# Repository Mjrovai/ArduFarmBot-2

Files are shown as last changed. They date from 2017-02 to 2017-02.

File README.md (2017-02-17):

# ArduFarmBot-2
Automatic Gardening System with NodeMCU and Blynk
<p> This complete tutorial can be found at: https://www.instructables.com/id/Automatic-Gardening-System-With-NodeMCU-and-Blynk-/ </p>
<p>Some time ago, we developed a similar project: <a href="https://www.instructables.com/id/ArduFarmBot-Controlling-a-Tomato-Home-Farm-Using-A/">"ArduFarmBot: Controlling a Tomato Home Farm using Arduino and IoT"</a>. On this new version, the <strong><em>ArduFarmBot 2,</em></strong> the main specification of the original project will be kept. We will develop a fully automated Gardening System based on NodeMCU ESP8266 and an IoT app, the BLYNK. </p><p>Basically, information from a plantation will be captured, temperature and humidity, both from air and soil. Based on those data, the ArduFarmBot 2 will decide the right amount (and when) the plantation should receive heat and water. Also the project should allow manual intervention of an operator in order to control a water pump and an electric lamp to generate heat for the plantation. The manual intervention must be both, local and remote via Internet.</p><p>In short, the system should receive as<strong> input</strong>:</p><ul>           
<li>Sensors:           
<ul>           
<li>Air Temperature               
</li><li>Air Relative Humidity                     
</li><li>Soil Temperature
</li><li>Soil Moisture (humidity)</li></ul></li></ul><ul> 
<li>Buttons:           
<ul>           
<li>Pump ON/OFF              
</li><li>Lamp ON/OFF</li></ul></li></ul><p>The system should provide as an <strong>output</strong>:</p><ul>           
<li>Actuators:           
<ul>           
<li>Relay for Pump control              
</li><li>Relay for Lamp control</li></ul></li></ul><ul> 
<li>Messages
<ul>
<li>Automatic messages must be sent on main events as:
<ul>
<li>Pump ON
</li><li>Lamo On
</li><li>System Off-line </li></ul></li></ul></li></ul><ul>
<li>Data Display           
<ul>           
<li>All analog and digital data should be available for instant  evaluation</li></ul></li></ul><ul> 
<li>Data Storage
<ul>
<li>
<p>Historic data should be storage remotely</p></li></ul></li></ul><p>The block diagram shows the main components of the project.</p>

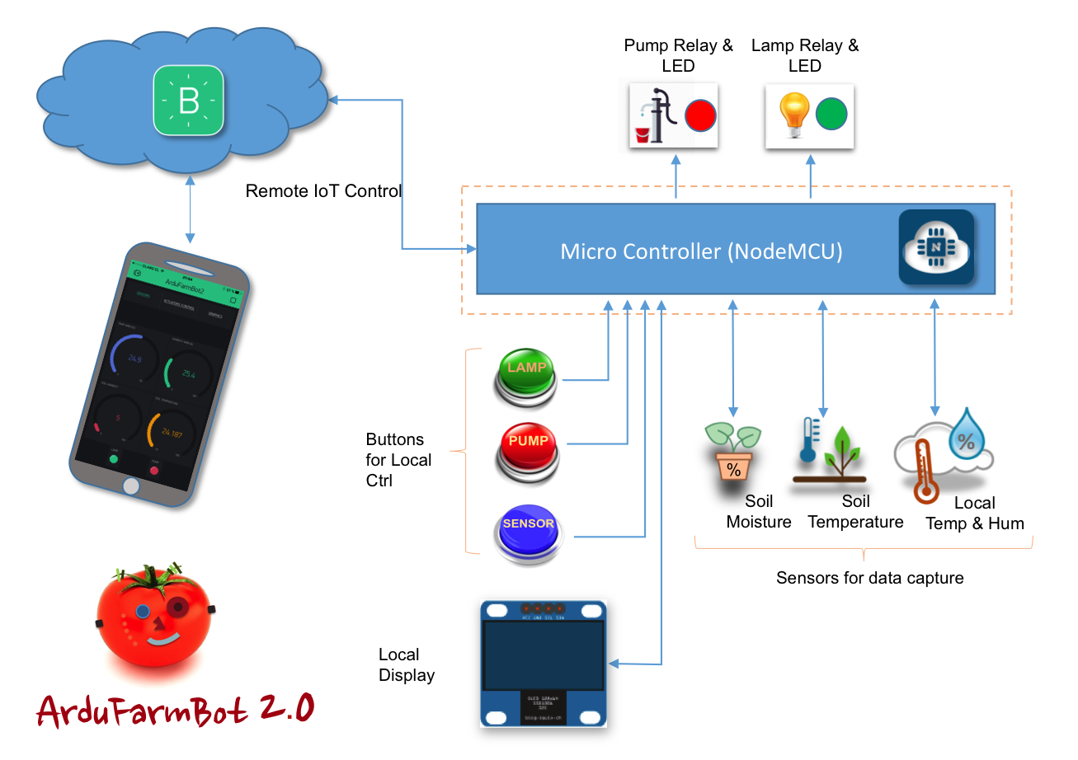
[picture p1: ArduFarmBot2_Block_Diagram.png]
ArduFarmBot2 Block Diagram


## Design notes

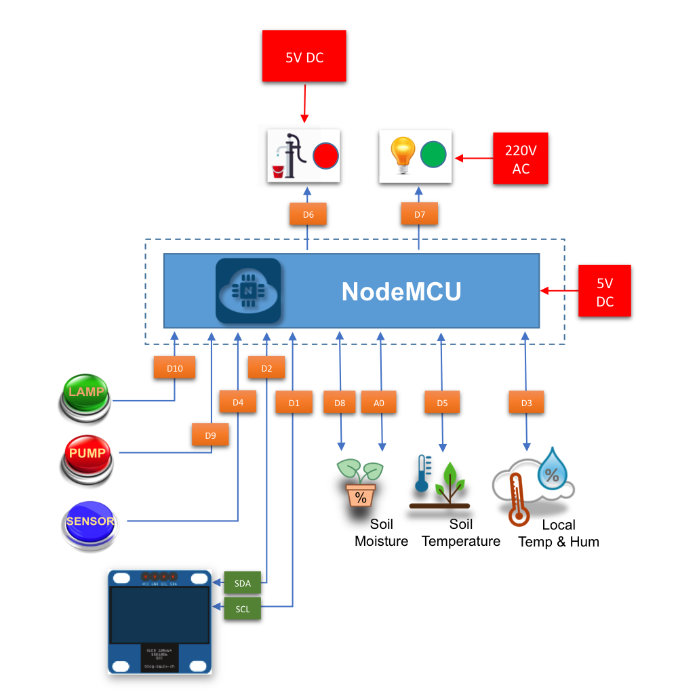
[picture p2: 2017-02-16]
ArduFarmBot2_Pin_Diagram.png

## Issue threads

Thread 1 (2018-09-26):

LM393 Soil moisture value.

juliobarbagallo, 2018-09-26:
Hi Marcelo,
    How are you?
I am not pretty sure if its an issue, but its the only way I figured it out to contact you.
This is my first time trying on IoT projects and I am trying to follow yours. Thanks for sharing it.
I need to see if you can help me out here, I was perfect until Soil Moisture step. Didn't try it at soil, just in the air, but I got Soil= -169% I am not sure what I am doing wrong. If you could try to guide me here would be great.
Thanks in advance and thanks again for sharing, I am really amused with your work.
Regards. Julio.
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

drinkwater2018, 2018-09-29:
Hi Mjrovai,

I am also on same page, its taking hell of time to figure out what's wrong
in the code and my sensor, I am not able to exicute the out for wifi and
for relay I installed driver for.wifi and i still not able to follow the
words mjbot forum.

Please help me you reached next level, I have extactly did what you did but
not any thing further, I thank you for followup I hope we can both figure
it out and resolve the issue and learn

Thanks
Water

On Wed, Sep 26, 2018, 6:38 PM juliobarbagallo <notifications@github.com>
wrote:

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

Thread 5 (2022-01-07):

Error in compiling in Mac OSX: ESP8266WiFi and DHT22

andreltr, 2022-01-07:
Hello,

I'm trying to compile the software on my Macbook Pro to no avail.
Settings:
Additional URLs: https://arduino.esp8266.com/stable/package_esp8266com_index.json,https://dl.espressif.com/dl/package_esp32_index.json,http://arduino.esp8266.com/stable/package_esp8266com_index.json,https://raw.githubusercontent.com/esp8266/esp8266.github.io/master/stable/package_esp8266com_index.json

The errors are shown below,

Board:
ESP32 Dev Module

The error appears in the following line:

/* ESP */
#include <ESP8266WiFi.h>

Arduino: 1.8.20 Hourly Build 2021/12/20 07:34 (Mac OS X), Board: "ESP32 Dev Module, Disabled, Default 4MB with spiffs (1.2MB APP/1.5MB SPIFFS), 240MHz (WiFi/BT), QIO, 80MHz, 4MB (32Mb), 921600, None"
ArduFarmBot2_Local_Automatic_Ctrl_V2:18:25: fatal error: ESP8266WiFi.h: No such file or directory
compilation terminated.
exit status 1
ESP8266WiFi.h: No such file or directory

Board:
Generic ESP8266 Module

Error shown in stationDefines.h:
Arduino: 1.8.20 Hourly Build 2021/12/20 07:34 (Mac OS X), Board: "Generic ESP8266 Module, 80 MHz, Flash, Disabled (new aborts on oom), Disabled, All SSL ciphers (most compatible), 32KB cache + 32KB IRAM (balanced), Use pgm_read macros for IRAM/PROGMEM, dtr (aka nodemcu), 26 MHz, 40MHz, DOUT (compatible), 1MB (FS:64KB OTA:~470KB), 2, nonos-sdk 2.2.1+100 (190703), v2 Lower Memory, Disabled, None, Only Sketch, 115200"

In file included from /Users/andreltr/Documents/IoT/Garduino/Automatic Gardening System With NodeMCU and Blynk/github_v2/ArduFarmBot2_Local_Automatic_Ctrl_V2/ArduFarmBot2_Local_Automatic_Ctrl_V2.ino:15:
stationDefines.h:23:16: error: 'D3' was not declared in this scope
   23 | #define DHTPIN D3
      |                ^~
/Users/andreltr/Documents/IoT/Garduino/Automatic Gardening System With NodeMCU and Blynk/github_v2/ArduFarmBot2_Local_Automatic_Ctrl_V2/ArduFarmBot2_Local_Automatic_Ctrl_V2.ino:31:9: note: in expansion of macro 'DHTPIN'
   31 | DHT dht(DHTPIN, DHTTYPE);
      |         ^~~~~~
/Users/andreltr/Documents/IoT/Garduino/Automatic Gardening System With NodeMCU and Blynk/github_v2/ArduFarmBot2_Local_Automatic_Ctrl_V2/ArduFarmBot2_Local_Automatic_Ctrl_V2.ino: In function 'void setup()':
stationDefines.h:38:18: error: 'D6' was not declared in this scope
   38 | #define PUMP_PIN D6              //PUMP (Red LED)
      |                  ^~
/Users/andreltr/Documents/IoT/Garduino/Automatic Gardening System With NodeMCU and Blynk/github_v2/ArduFarmBot2_Local_Automatic_Ctrl_V2/ArduFarmBot2_Local_Automatic_Ctrl_V2.ino:47:11: note: in expansion of macro 'PUMP_PIN'
   47 |   pinMode(PUMP_PIN, OUTPUT);
      |           ^~~~~~~~
stationDefines.h:39:18: error: 'D7' was not declared in this scope
   39 | #define LAMP_PIN D7              //LAMP (Green LED)
      |                  ^~
/Users/andreltr/Documents/IoT/Garduino/Automatic Gardening System With NodeMCU and Blynk/github_v2/ArduFarmBot2_Local_Automatic_Ctrl_V2/ArduFarmBot2_Local_Automatic_Ctrl_V2.ino:48:11: note: in expansion of macro 'LAMP_PIN'
   48 |   pinMode(LAMP_PIN, OUTPUT);
      |           ^~~~~~~~
stationDefines.h:44:24: error: 'D9' was not declared in this scope
   44 | #define PUMP_ON_BUTTON D9        //push-button PUMP (Red)
      |                        ^~
/Users/andreltr/Documents/IoT/Garduino/Automatic Gardening System With NodeMCU and Blynk/github_v2/ArduFarmBot2_Local_Automatic_Ctrl_V2/ArduFarmBot2_Local_Automatic_Ctrl_V2.ino:49:11: note: in expansion of macro 'PUMP_ON_BUTTON'
   49 |   pinMode(PUMP_ON_BUTTON, INPUT_PULLUP);
      |           ^~~~~~~~~~~~~~
stationDefines.h:45:24: error: 'D10' was not declared in this scope; did you mean 'B10'?
   45 | #define LAMP_ON_BUTTON D10       //push-button LAMP (Green)
      |                        ^~~
/Users/andreltr/Documents/IoT/Garduino/Automatic Gardening System With NodeMCU and Blynk/github_v2/ArduFarmBot2_Local_Automatic_Ctrl_V2/ArduFarmBot2_Local_Automatic_Ctrl_V2.ino:50:11: note: in expansion of macro 'LAMP_ON_BUTTON'
   50 |   pinMode(LAMP_ON_BUTTON, INPUT_PULLUP);
      |           ^~~~~~~~~~~~~~
stationDefines.h:46:29: error: 'D4' was not declared in this scope
   46 | #define SENSORS_READ_BUTTON D4   //push-button SENSOR (yellow)
      |                             ^~
/Users/andreltr/Documents/IoT/Garduino/Automatic Gardening System With NodeMCU and Blynk/github_v2/ArduFarmBot2_Local_Automatic_Ctrl_V2/ArduFarmBot2_Local_Automatic_Ctrl_V2.ino:51:11: note: in expansion of macro 'SENSORS_READ_BUTTON'
   51 |   pinMode(SENSORS_READ_BUTTON, INPUT_PULLUP);
      |           ^~~~~~~~~~~~~~~~~~~
stationDefines.h:30:24: error: 'D8' was not declared in this scope; did you mean 's8'?
   30 | #define soilMoisterVcc D8
      |                        ^~
/Users/andreltr/Documents/IoT/Garduino/Automatic Gardening System With NodeMCU and Blynk/github_v2/ArduFarmBot2_Local_Automatic_Ctrl_V2/ArduFarmBot2_Local_Automatic_Ctrl_V2.ino:52:11: note: in expansion of macro 'soilMoisterVcc'
   52 |   pinMode(soilMoisterVcc, OUTPUT);
      |           ^~~~~~~~~~~~~~
/Users/andreltr/Documents/IoT/Garduino/Automatic Gardening System With NodeMCU and Blynk/github_v2/ArduFarmBot2_Local_Automatic_Ctrl_V2/ArduFarmBot2_Local_Automatic_Ctrl_V2.ino: In function 'void readLocalCmd()':
stationDefines.h:44:24: error: 'D9' was not declared in this scope
   44 | #define PUMP_ON_BUTTON D9        //push-button PUMP (Red)
      |                        ^~
/Users/andreltr/Documents/IoT/Garduino/Automatic Gardening System With NodeMCU and Blynk/github_v2/ArduFarmBot2_Local_Automatic_Ctrl_V2/ArduFarmBot2_Local_Automatic_Ctrl_V2.ino:77:32: note: in expansion of macro 'PUMP_ON_BUTTON'
   77 |   boolean digiValue = debounce(PUMP_ON_BUTTON);
      |                                ^~~~~~~~~~~~~~
stationDefines.h:45:24: error: 'D10' was not declared in this scope; did you mean 'B10'?
   45 | #define LAMP_ON_BUTTON D10       //push-button LAMP (Green)
      |                        ^~~
/Users/andreltr/Documents/IoT/Garduino/Automatic Gardening System With NodeMCU and Blynk/github_v2/ArduFarmBot2_Local_Automatic_Ctrl_V2/ArduFarmBot2_Local_Automatic_Ctrl_V2.ino:84:24: note: in expansion of macro 'LAMP_ON_BUTTON'
   84 |   digiValue = debounce(LAMP_ON_BUTTON);
      |                        ^~~~~~~~~~~~~~
stationDefines.h:46:29: error: 'D4' was not declared in this scope
   46 | #define SENSORS_READ_BUTTON D4   //push-button SENSOR (yellow)
      |                             ^~
/Users/andreltr/Documents/IoT/Garduino/Automatic Gardening System With NodeMCU and Blynk/github_v2/ArduFarmBot2_Local_Automatic_Ctrl_V2/ArduFarmBot2_Local_Automatic_Ctrl_V2.ino:91:24: note: in expansion of macro 'SENSORS_READ_BUTTON'
   91 |   digiValue = debounce(SENSORS_READ_BUTTON);
      |                        ^~~~~~~~~~~~~~~~~~~
/Users/andreltr/Documents/IoT/Garduino/Automatic Gardening System With NodeMCU and Blynk/github_v2/ArduFarmBot2_Local_Automatic_Ctrl_V2/ArduFarmBot2_Local_Automatic_Ctrl_V2.ino: In function 'void aplyCmd()':
stationDefines.h:38:18: error: 'D6' was not declared in this scope
   38 | #define PUMP_PIN D6              //PUMP (Red LED)
      |                  ^~
/Users/andreltr/Documents/IoT/Garduino/Automatic Gardening System With NodeMCU and Blynk/github_v2/ArduFarmBot2_Local_Automatic_Ctrl_V2/ArduFarmBot2_Local_Automatic_Ctrl_V2.ino:114:18: note: in expansion of macro 'PUMP_PIN'
  114 |     digitalWrite(PUMP_PIN, HIGH);
      |                  ^~~~~~~~
stationDefines.h:38:18: error: 'D6' was not declared in this scope
   38 | #define PUMP_PIN D6              //PUMP (Red LED)
      |                  ^~
/Users/andreltr/Documents/IoT/Garduino/Automatic Gardening System With NodeMCU and Blynk/github_v2/ArduFarmBot2_Local_Automatic_Ctrl_V2/ArduFarmBot2_Local_Automatic_Ctrl_V2.ino:119:22: note: in expansion of macro 'PUMP_PIN'
  119 |         digitalWrite(PUMP_PIN, LOW);
      |                      ^~~~~~~~
stationDefines.h:39:18: error: 'D7' was not declared in this scope
   39 | #define LAMP_PIN D7              //LAMP (Green LED)
      |                  ^~
/Users/andreltr/Documents/IoT/Garduino/Automatic Gardening System With NodeMCU and Blynk/github_v2/ArduFarmBot2_Local_Automatic_Ctrl_V2/ArduFarmBot2_Local_Automatic_Ctrl_V2.ino:125:18: note: in expansion of macro 'LAMP_PIN'
  125 |     digitalWrite(LAMP_PIN, HIGH);
      |                  ^~~~~~~~
stationDefines.h:39:18: error: 'D7' was not declared in this scope
   39 | #define LAMP_PIN D7              //LAMP (Green LED)
      |                  ^~
/Users/andreltr/Documents/IoT/Garduino/Automatic Gardening System With NodeMCU and Blynk/github_v2/ArduFarmBot2_Local_Automatic_Ctrl_V2/ArduFarmBot2_Local_Automatic_Ctrl_V2.ino:130:22: note: in expansion of macro 'LAMP_PIN'
  130 |         digitalWrite(LAMP_PIN, LOW);
      |                      ^~~~~~~~
/Users/andreltr/Documents/IoT/Garduino/Automatic Gardening System With NodeMCU and Blynk/github_v2/ArduFarmBot2_Local_Automatic_Ctrl_V2/generalFunctions.ino: In function 'void waitButtonPress(int)':
stationDefines.h:46:29: error: 'D4' was not declared in this scope
   46 | #define SENSORS_READ_BUTTON D4   //push-button SENSOR (yellow)
      |                             ^~
/Users/andreltr/Documents/IoT/Garduino/Automatic Gardening System With NodeMCU and Blynk/github_v2/ArduFarmBot2_Local_Automatic_Ctrl_V2/generalFunctions.ino:8:19: note: in expansion of macro 'SENSORS_READ_BUTTON'
    8 |   while (debounce(SENSORS_READ_BUTTON))
      |                   ^~~~~~~~~~~~~~~~~~~
/Users/andreltr/Documents/IoT/Garduino/Automatic Gardening System With NodeMCU and Blynk/github_v2/ArduFarmBot2_Local_Automatic_Ctrl_V2/getSensors.ino: In function 'void getSoilMoisterData()':
stationDefines.h:30:24: error: 'D8' was not declared in this scope; did you mean 's8'?
   30 | #define soilMoisterVcc D8
      |                        ^~
/Users/andreltr/Documents/IoT/Garduino/Automatic Gardening System With NodeMCU and Blynk/github_v2/ArduFarmBot2_Local_Automatic_Ctrl_V2/getSensors.ino:25:17: note: in expansion of macro 'soilMoisterVcc'
   25 |   digitalWrite (soilMoisterVcc, HIGH);
      |                 ^~~~~~~~~~~~~~
exit status 1
'D3' was not declared in this scope

Board NodeMCU 1.0 (ESP-12E Module)

Error shown

Arduino: 1.8.20 Hourly Build 2021/12/20 07:34 (Mac OS X), Board: "Generic ESP8266 Module, 80 MHz, Flash, Disabled (new aborts on oom), Disabled, All SSL ciphers (most compatible), 32KB cache + 32KB IRAM (balanced), Use pgm_read macros for IRAM/PROGMEM, dtr (aka nodemcu), 26 MHz, 40MHz, DOUT (compatible), 1MB (FS:64KB OTA:~470KB), 2, nonos-sdk 2.2.1+100 (190703), v2 Lower Memory, Disabled, None, Only Sketch, 115200"

fork/exec /Users/andreltr/Library/Arduino15/packages/esp8266/tools/xtensa-lx106-elf-gcc/3.0.3-gcc10.3-9bcba0b/bin/xtensa-lx106-elf-g++: no such file or directory
Error compiling for board NodeMCU 1.0 (ESP-12E Module).
Could not find boards.txt in /Users/andreltr/Library/Arduino15/packages/esp8266/hardware/esp8266/3.0.2. Is it pre-1.5?

Question: what is the correct board to use or which setting/library is missing, please?

André Luiz

andreltr, 2022-01-08:
Hello,
I found the correct board and it is NodeMCU 1.0 (ESP 12E Module).
All problems solved.

Closed 2022-01-08.

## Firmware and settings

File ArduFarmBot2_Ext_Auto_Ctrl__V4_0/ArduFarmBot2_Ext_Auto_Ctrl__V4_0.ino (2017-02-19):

/***************************************************************************************************************
 *  ArduFarmBot using NodeMCU ESP-12 Develop Kit V1.0
 *  DHT connected to NodeMCU pin D3 (Ambient Temperature and Relative Humidity)
 *  Soil Moister Sensor connected to A0
 *  Sensor Data on local OLED Display
 *  Local Command via buttons 
 *  OLED Display is off as default. Press Sensor Button to update and display data
 *  Introduced the function "waitButtonPress (int waitTime)", to break initial loop
 *  Automatic Local Control
 *  Display automatic set-up parameters at Start-up
 *  Sensor data sent to Blynk app
 *  Control commands received from Blynk app
 *  Downloads, docs, tutorials: http://www.blynk.cc
 *  Blynk library is licensed under MIT license
 *  
 *  V4.0 Invert the logic to use Relay module that works from HIGH to LOW
 *       
 *  MJRoBot Version 4.0 - Automatic and Remote Control - Logic LOW -  Developed by MJRovai 16 Feb 2017
 ********************************************************************************************************************************/
#define SW_VERSION "   SW Ver. 4.0" // SW version will appears at innitial LCD Display
#include "stationDefines.h"       // Project definitions
#include "stationCredentials.h"

/* ESP & Blynk */
#define BLYNK_PRINT Serial    // Comment this out to disable prints and save space
#include <ESP8266WiFi.h>
#include <BlynkSimpleEsp8266.h>
WidgetLED PUMPs(V0);  // Echo signal to Sensors Tab at Blynk App
WidgetLED PUMPa(V5); // Echo signal to Actuators Tab at Blynk App
WidgetLED LAMPs(V1);  // Echo signal to Sensors Tab at Blynk App
WidgetLED LAMPa(V6); // Echo signal to Actuators Tab at Blynk App

/* TIMER */
#include <SimpleTimer.h>
SimpleTimer timer;

/* OLED */
#include <ACROBOTIC_SSD1306.h> // library for OLED: SCL ==> D1; SDA ==> D2
#include <SPI.h>
#include <Wire.h>

/* DHT22*/
#include "DHT.h"
DHT dht(DHTPIN, DHTTYPE);

/* DS18B20 Temperature Sensor */
#include <OneWire.h>
#include <DallasTemperature.h>
OneWire oneWire(ONE_WIRE_BUS);
DallasTemperature DS18B20(&oneWire);

void setup()
{
  Serial.begin(115200);
  delay(10);
  Serial.println("ArduFarmBot 2");
  Serial.println(".... Starting Setup");
  Serial.println(" ");

  pinMode(PUMP_PIN, OUTPUT);
  pinMode(LAMP_PIN, OUTPUT);
  pinMode(PUMP_ON_BUTTON, INPUT_PULLUP);
  pinMode(LAMP_ON_BUTTON, INPUT_PULLUP);
  pinMode(SENSORS_READ_BUTTON, INPUT_PULLUP);
  pinMode(soilMoisterVcc, OUTPUT);
  
  Blynk.begin(auth, ssid, pass);
  oledStart();
  dht.begin();
  DS18B20.begin();

  PUMPs.off();
  LAMPs.off();
  PUMPa.off();
  LAMPa.off();
  digitalWrite(PUMP_PIN, HIGH); // To be used with Relay module (inverted logic: normally HIGH)
  digitalWrite(LAMP_PIN, HIGH); // To be used with Relay module (inverted logic: normally HIGH)
  digitalWrite (soilMoisterVcc, LOW);
  
  waitButtonPress (SHOW_SET_UP); // Wait for Sensor Button to be pressed 
  oled.clearDisplay();
  startTimers();
}

void loop()
{
  timer.run(); // Initiates SimpleTimer
  Blynk.run();
}

/****************************************************************
* Read remote commands 
****************************************************************/
BLYNK_WRITE(3) // Pump remote control
{
  int i=param.asInt();
  if (i==1) 
  {
    pumpStatus = !pumpStatus;
    aplyCmd();
  }
}

BLYNK_WRITE(4) // Lamp remote control
{
  int i=param.asInt();
  if (i==1) 
  {
    lampStatus = !lampStatus;
    aplyCmd();
  }
}

/****************************************************************
* Read local commands (Pump and Lamp buttons are normally "HIGH"):
****************************************************************/
void readLocalCmd() 
{  
  boolean digiValue = debounce(PUMP_ON_BUTTON);
  if (!digiValue) 
  {
    pumpStatus = !pumpStatus;
    aplyCmd();
  }

  digiValue = debounce(LAMP_ON_BUTTON);
  if (!digiValue) 
  {
    lampStatus = !lampStatus;
    aplyCmd();
  }

  digiValue = debounce(SENSORS_READ_BUTTON);
  if (!digiValue) 
  {
    turnOffOLED = !turnOffOLED;
    if (!turnOffOLED)
    {
      oled.setTextXY(0,0); oled.putString("UPDATING SENSORS");
      getDhtData();
      getSoilMoisterData();
      getSoilTempData();
      oledStart();
      displayData();
    }else oled.clearDisplay();
  }
}

/***************************************************
* Receive Commands and act on RELAYs - Logic LOW
****************************************************/
void aplyCmd()
{
  if (pumpStatus == 1) 
  {
    Blynk.notify("ArduFarmBot2: Warning ==>> Pump ON"); 
    digitalWrite(PUMP_PIN, LOW); // To be used with Relay module (inverted logic: activate with LOW)
    if (!turnOffOLED) displayData();
    PUMPs.on();
    PUMPa.on();
  }
  else
      {
        digitalWrite(PUMP_PIN, HIGH); // To be used with Relay module (inverted logic: normally HIGH)
        if (!turnOffOLED) displayData();
        PUMPs.off();
        PUMPa.off();
      }
  
  if (lampStatus == 1) 
  {
    Blynk.notify("ArduFarmBot2: Warning ==>> Lamp ON");
    digitalWrite(LAMP_PIN, LOW); // To be used with Relay module (inverted logic: activate with LOW)
    if (!turnOffOLED) displayData();
    LAMPs.on();
    LAMPa.on();
  }
  else
      {
        digitalWrite(LAMP_PIN, HIGH); // To be used with Relay module (inverted logic: normally HIGH)
        if (!turnOffOLED) displayData();
        LAMPs.off();
        LAMPa.off();
      }
}

/***************************************************
* Automatically Control the Plantation based on sensors reading
****************************************************/
void autoControlPlantation(void)
{ 
  if (soilMoister < DRY_SOIL) 
  {
    turnPumpOn();
  }

  if (airTemp < COLD_TEMP) 
  {
    turnLampOn();
  }
}

/***************************************************
* Turn Pump On for a certain amount of time
****************************************************/
void turnPumpOn()
{
  pumpStatus = 1;
  aplyCmd();
  delay (TIME_PUMP_ON*1000);
  pumpStatus = 0;
  aplyCmd();
}

/***************************************************
* Turn Lamp On for a certain amount of time 
****************************************************/
void turnLampOn()
{
  lampStatus = 1;
  aplyCmd();
  delay (TIME_LAMP_ON*1000);
  lampStatus = 0;
  aplyCmd();
}

/***************************************************
 * Send data to Blynk
 **************************************************/
void sendUptime()
{
  Blynk.virtualWrite(10, airTemp); //virtual pin V10
  Blynk.virtualWrite(11, airHum); // virtual pin V11
  Blynk.virtualWrite(12, soilMoister); // virtual pin V12
  Blynk.virtualWrite(13, soilTemp); //virtual pin V13
}

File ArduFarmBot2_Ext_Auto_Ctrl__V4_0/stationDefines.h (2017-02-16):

/* Automatic Control Parameters Definition */
#define DRY_SOIL      66
#define WET_SOIL      85
#define COLD_TEMP     12
#define HOT_TEMP      22
#define TIME_PUMP_ON  15
#define TIME_LAMP_ON  15

/* TIMER */
#define READ_BUTTONS_TM   1L  // definitions in seconds
#define READ_SOIL_TEMP_TM 2L
#define READ_SOIL_HUM_TM  10L
#define READ_AIR_DATA_TM  2L
#define SEND_UP_DATA_TM   10L
#define AUTO_CTRL_TM      60L     

/* OLED */
boolean turnOffOLED = 1;
#define SHOW_SET_UP   30

/* DHT22*/
#define DHTPIN D3  
#define DHTTYPE DHT22 
float airHum = 0;
float airTemp = 0;

/* Soil Moister */
#define soilMoisterPin A0
#define soilMoisterVcc D8
int soilMoister = 0;

/* DS18B20 Temperature Sensor */
#define ONE_WIRE_BUS 14 // DS18B20 on NodeMCU pin D5 corresponds to GPIO 014 on Arduino
float soilTemp;

/* Relays */
#define PUMP_PIN D6              //PUMP (Red LED)
#define LAMP_PIN D7              //LAMP (Green LED)
boolean pumpStatus = 0;
boolean lampStatus = 0;

/* Buttons */
#define PUMP_ON_BUTTON D9        //push-button PUMP (Red)
#define LAMP_ON_BUTTON D10       //push-button LAMP (Green)
#define SENSORS_READ_BUTTON D4   //push-button SENSOR (yellow)

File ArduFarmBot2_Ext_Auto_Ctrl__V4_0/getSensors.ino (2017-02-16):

/***************************************************
 * Get DHT data
 **************************************************/
void getDhtData(void)
{
  float tempIni = airTemp;
  float humIni = airHum;
  airTemp = dht.readTemperature();
  airHum = dht.readHumidity();
  if (isnan(airHum) || isnan(airTemp))   // Check if any reads failed and exit early (to try again).
  {
    Serial.println("Failed to read from DHT sensor!");
    airTemp = tempIni;
    airHum = humIni;
    return;
  }
}

/***************************************************
 * Get Soil Moister Sensor data
 **************************************************/
void getSoilMoisterData(void)
{
  soilMoister = 0;
  digitalWrite (soilMoisterVcc, HIGH);
  delay (500);
  int N = 3;
  for(int i = 0; i < N; i++) // read sensor "N" times and get the average
  {
    soilMoister += analogRead(soilMoisterPin);   
    delay(150);
  }
  digitalWrite (soilMoisterVcc, LOW);
  soilMoister = soilMoister/N; 
  soilMoister = map(soilMoister, 600, 0, 0, 100); //LM393 on 5V (+Vin)
}

/***************************************************
 * Get SoilTemp sensor data
 **************************************************/
void getSoilTempData()
{
  DS18B20.requestTemperatures(); 
  soilTemp = DS18B20.getTempCByIndex(0);

  int newData = ((soilTemp + 0.05) * 10); //fix soilTemp value to 1 decimal place.
  soilTemp = (newData / 10.0);
}
